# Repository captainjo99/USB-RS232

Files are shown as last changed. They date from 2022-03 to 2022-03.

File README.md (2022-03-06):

# USB-RS232

Small USB to RS232 communication module designed in [KiCad](https://www.kicad.org/).

## Front view

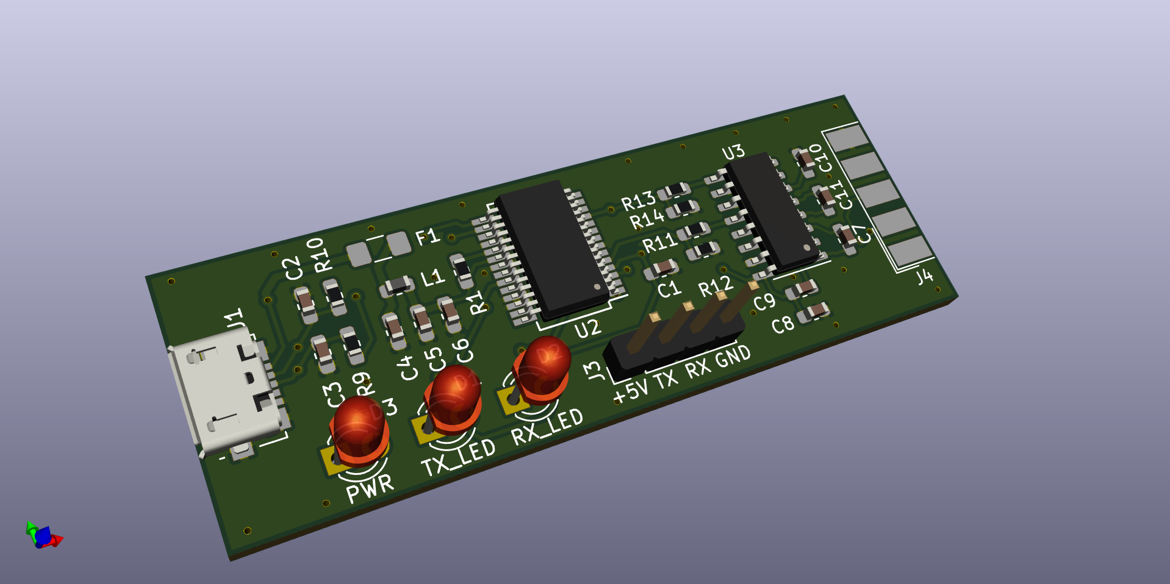
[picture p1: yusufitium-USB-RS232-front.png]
front view


## Back view

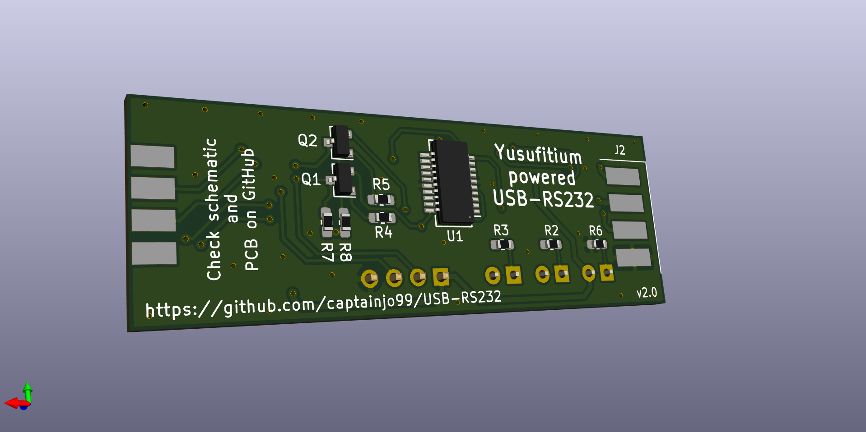
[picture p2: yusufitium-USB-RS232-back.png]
back view


## Notes

This module is based on FT232RL/FT231XS and MAX202.

Schematic is available in pdf format in the repository. Module features 3V3 to 5V level shifter. RX and TX on the pin header arer 5V TTL.

**ONLY USE FT232RL OR FT231XS, NOT BOTH AT THE SAME TIME. MODULE IS DESIGNED SO THEY CAN BE USED INTERCHANGEABLY!!!**

## Licence
Creative Commons Zero 1.0 Universal

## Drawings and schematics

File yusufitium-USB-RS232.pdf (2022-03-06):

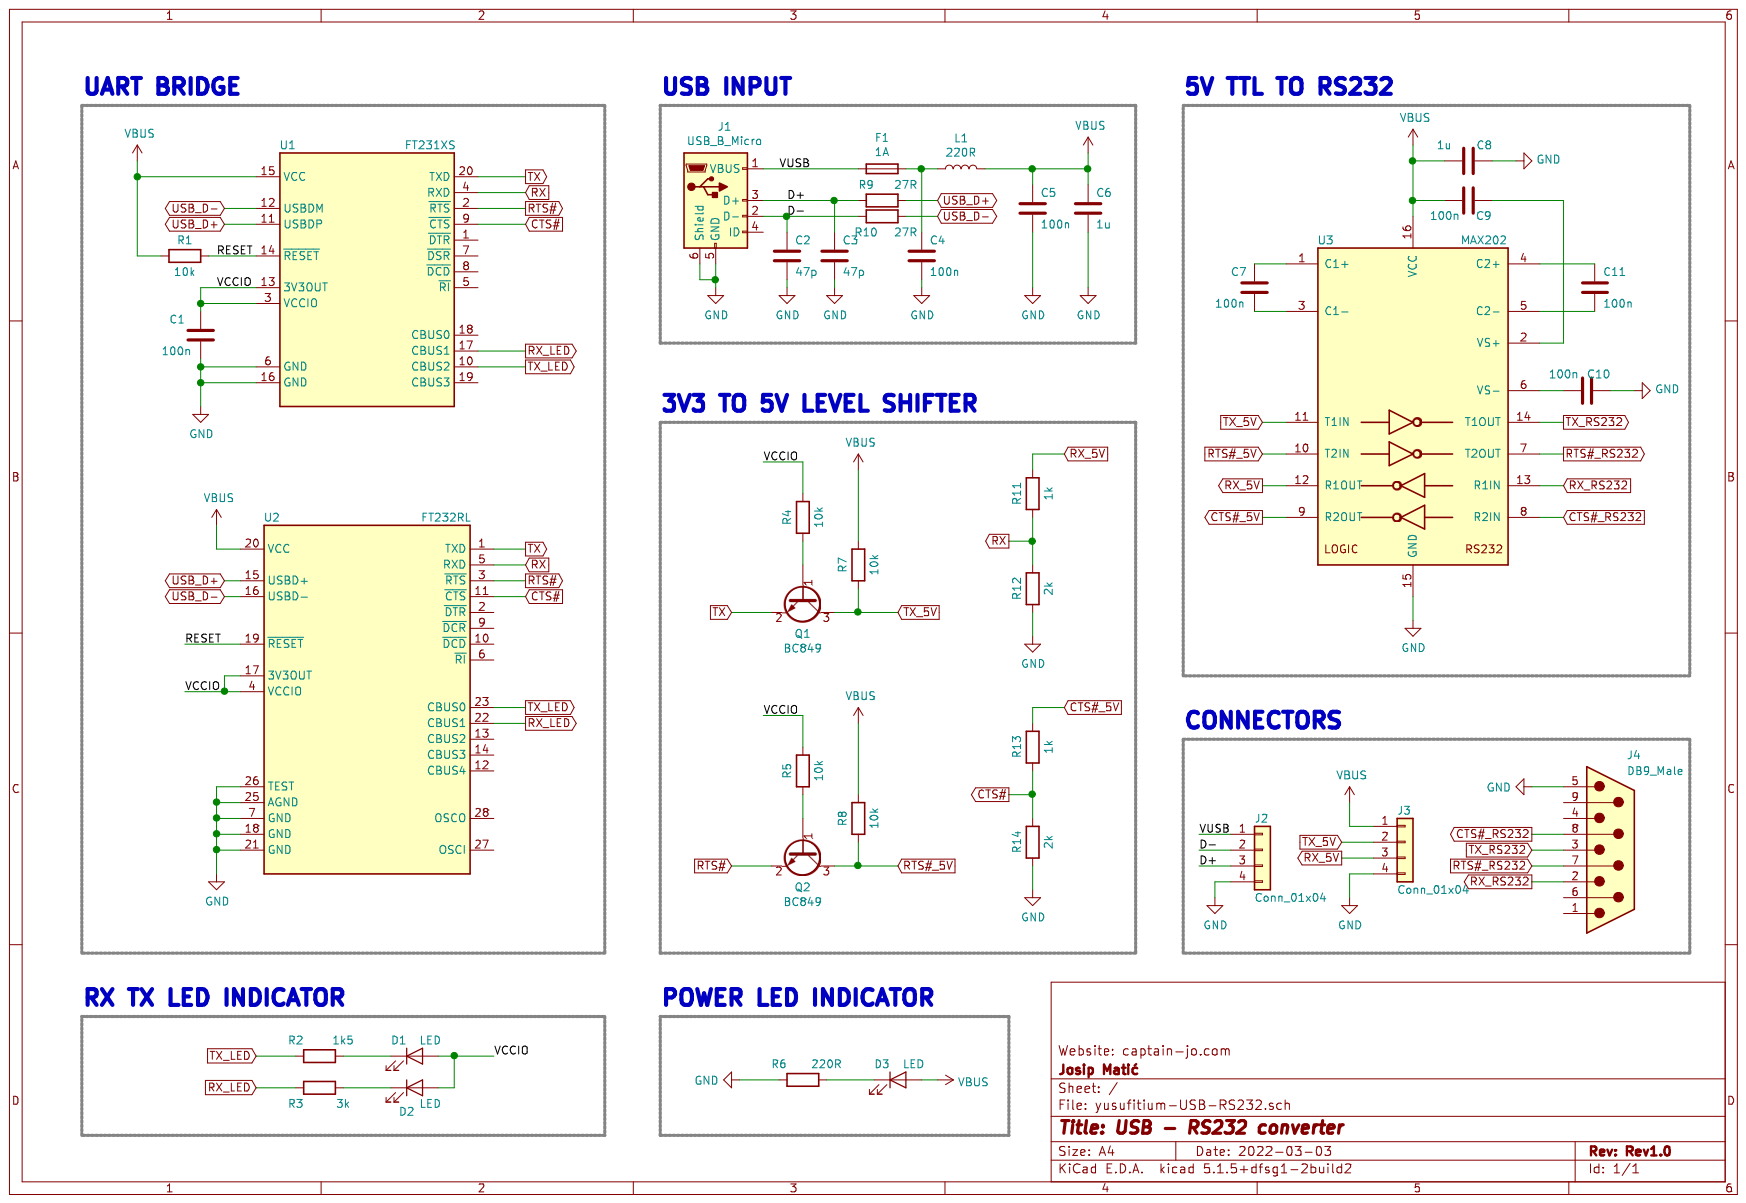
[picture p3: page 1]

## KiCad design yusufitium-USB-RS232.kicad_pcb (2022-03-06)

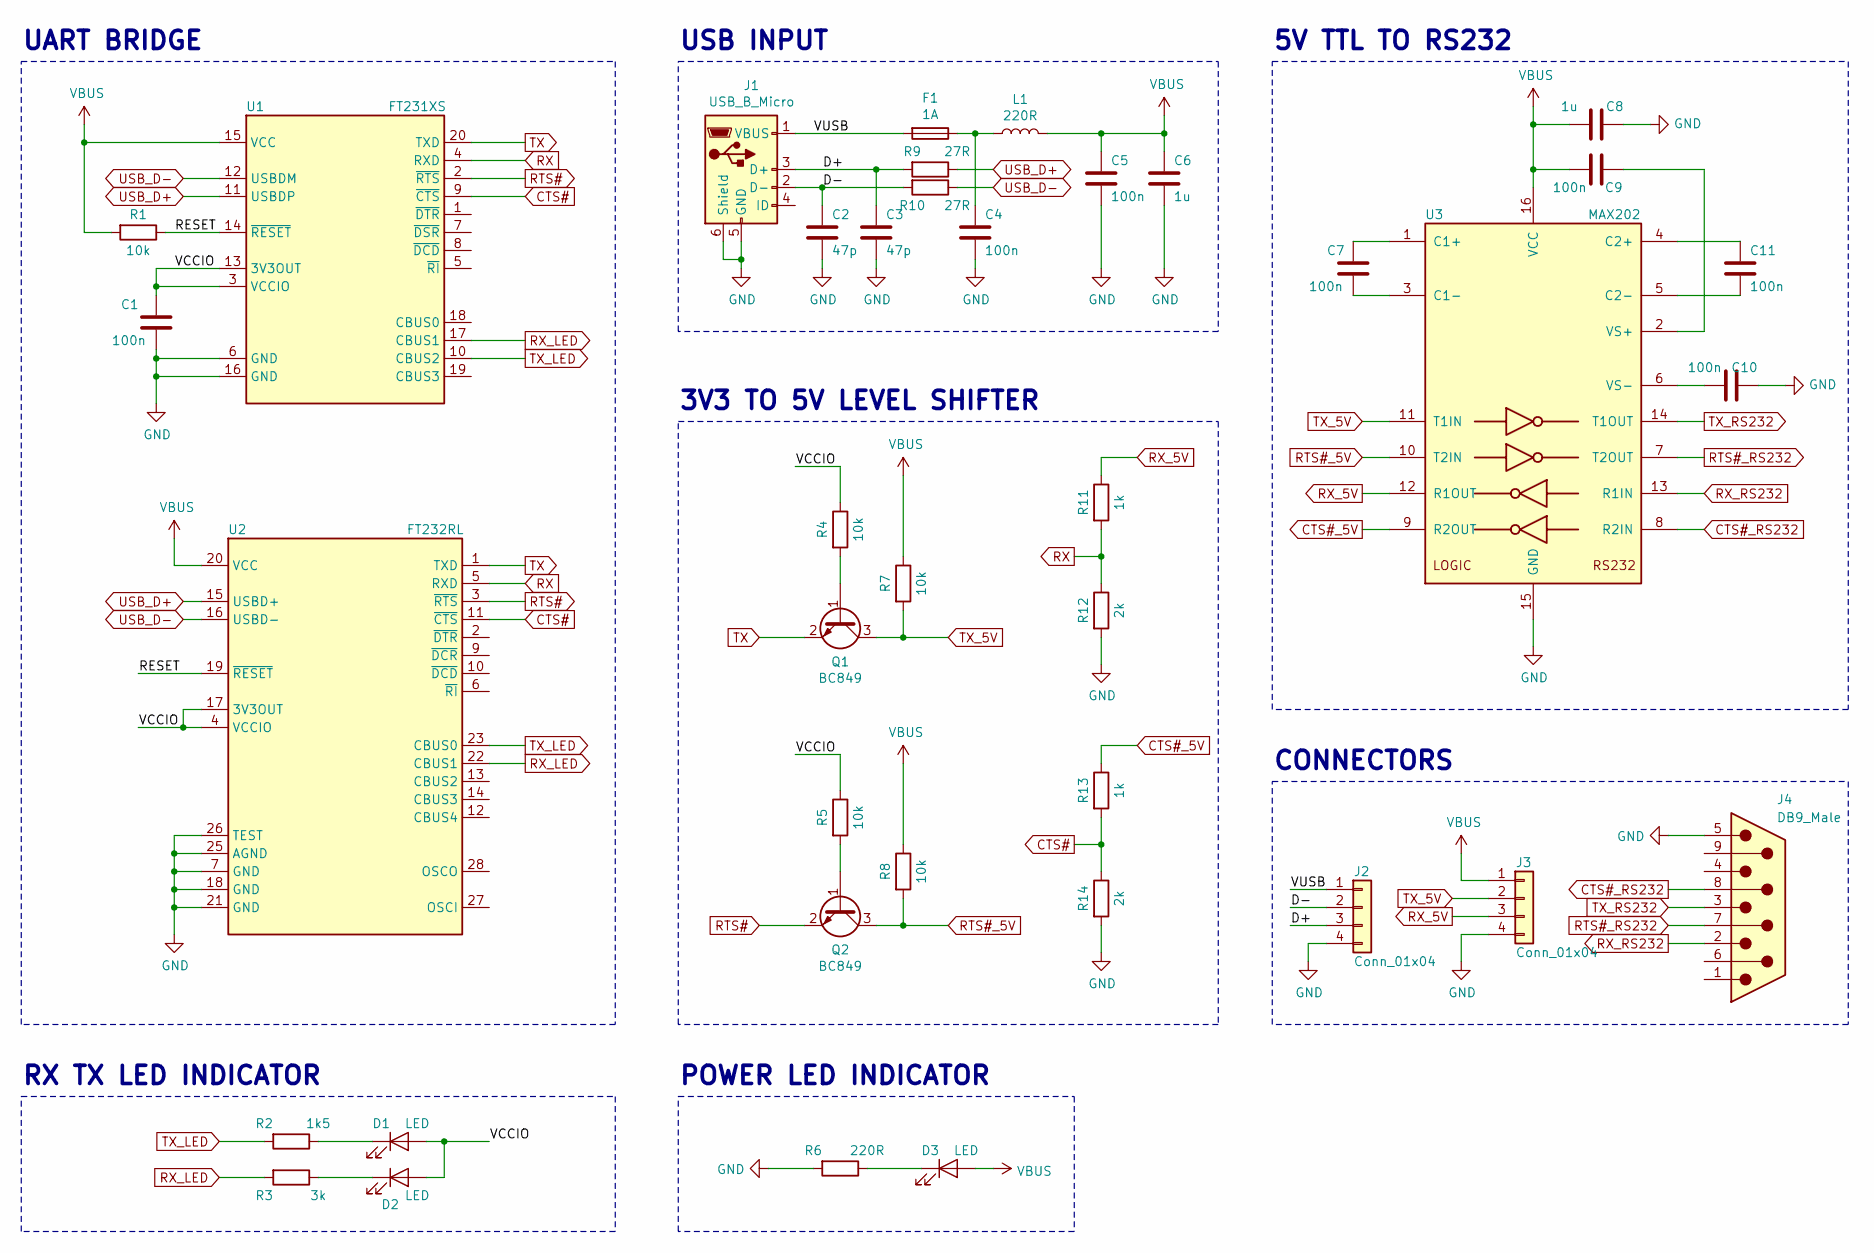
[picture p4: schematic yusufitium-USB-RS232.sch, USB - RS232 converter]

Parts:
C1, C4, C5, C7, C9, C10, C11: 100n; C_0603_1608Metric_Pad1.05x0.95mm_HandSolder
C2, C3: 47p; C_0603_1608Metric_Pad1.05x0.95mm_HandSolder
C6, C8: 1u; C_0603_1608Metric_Pad1.05x0.95mm_HandSolder
D1, D2, D3: LED; LED_D3.0mm
F1: 1A; Fuse_1206_3216Metric_Pad1.42x1.75mm_HandSolder
J1: USB_B_Micro; USB_Micro-B_Molex_47346-0001
J2: Conn_01x04; WireHeader_1x4
J3: Conn_01x04; PinHeader_1x04_P2.54mm_Vertical
J4: DB9_Male; DSUB-9_Male_EdgeMount_P2.77mm
L1: 220R; L_0603_1608Metric
Q1, Q2: BC849; SOT-23
R1, R4, R5, R7, R8: 10k; R_0603_1608Metric_Pad1.05x0.95mm_HandSolder
R2: 1k5; R_0603_1608Metric_Pad1.05x0.95mm_HandSolder
R3: 3k; R_0603_1608Metric_Pad1.05x0.95mm_HandSolder
R6: 220R; R_0603_1608Metric_Pad1.05x0.95mm_HandSolder
R9, R10: 27R; R_0603_1608Metric_Pad1.05x0.95mm_HandSolder
R11, R13: 1k; R_0603_1608Metric_Pad1.05x0.95mm_HandSolder
R12, R14: 2k; R_0603_1608Metric_Pad1.05x0.95mm_HandSolder
U1: FT231XS; SSOP-20_3.9x8.7mm_P0.635mm
U2: FT232RL; SSOP-28_5.3x10.2mm_P0.65mm
U3: MAX202; SOIC-16_3.9x9.9mm_P1.27mm

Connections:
/D+: C3.1, J1.3 (D+), J2.3, R9.2
/D-: C2.1, J1.2 (D-), J2.2, R10.2
/RESET: R1.1, U1.14 (~RESET), U2.19 (~RESET~)
/VCCIO: C1.1, D1.2 (A), D2.2 (A), R4.1, R5.1, U1.3 (VCCIO), U1.13 (3V3OUT), U2.4 (VCCIO), U2.17 (3V3OUT)
/VUSB: F1.2, J1.1 (VBUS), J2.1
CTS#: R13.2, R14.1, U1.9 (~CTS), U2.11 (~CTS)
CTS#_5V: R13.1, U3.9 (R2OUT)
CTS#_RS232: J4.8, U3.8 (R2IN)
GND: C1.2, C2.2, C3.2, C4.2, C5.2, C6.2, C8.1, C10.2, J1.5 (GND), J1.6 (Shield), J2.4, J3.4, J4.5, R6.2, R12.2, R14.2, U1.6 (GND), U1.16 (GND), U2.7 (GND), U2.18 (GND), U2.21 (GND), U2.25 (AGND), U2.26 (TEST), U3.15 (GND)
unnamed: C4.1, F1.1, L1.1
unnamed: C7.1, U3.1 (C1+)
unnamed: C7.2, U3.3 (C1-)
unnamed: C9.2, U3.2 (VS+)
unnamed: C10.1, U3.6 (VS-)
unnamed: C11.1, U3.4 (C2+)
unnamed: C11.2, U3.5 (C2-)
unnamed: D1.1 (K), R2.1
unnamed: D2.1 (K), R3.1
unnamed: D3.1 (K), R6.1
unnamed: Q1.1 (B), R4.2
unnamed: Q2.1 (B), R5.2
RTS#: Q2.2 (E), U1.2 (~RTS), U2.3 (~RTS)
RTS#_5V: Q2.3 (C), R8.2, U3.10 (T2IN)
RTS#_RS232: J4.7, U3.7 (T2OUT)
RX: R11.2, R12.1, U1.4 (RXD), U2.5 (RXD)
RX_5V: J3.3, R11.1, U3.12 (R1OUT)
RX_LED: R3.2, U1.17 (CBUS1), U2.22 (CBUS1)
RX_RS232: J4.2, U3.13 (R1IN)
TX: Q1.2 (E), U1.20 (TXD), U2.1 (TXD)
TX_5V: J3.2, Q1.3 (C), R7.2, U3.11 (T1IN)
TX_LED: R2.2, U1.10 (CBUS2), U2.23 (CBUS0)
TX_RS232: J4.3, U3.14 (T1OUT)
USB_D+: R9.1, U1.11 (USBDP), U2.15 (USBD+)
USB_D-: R10.1, U1.12 (USBDM), U2.16 (USBD-)
VBUS: C5.1, C6.1, C8.2, C9.1, D3.2 (A), J3.1, L1.2, R1.2, R7.1, R8.1, U1.15 (VCC), U2.20 (VCC), U3.16 (VCC)

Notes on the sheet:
UART BRIDGE
USB INPUT
3V3 TO 5V LEVEL SHIFTER
5V TTL TO RS232
CONNECTORS
RX TX LED INDICATOR
POWER LED INDICATOR

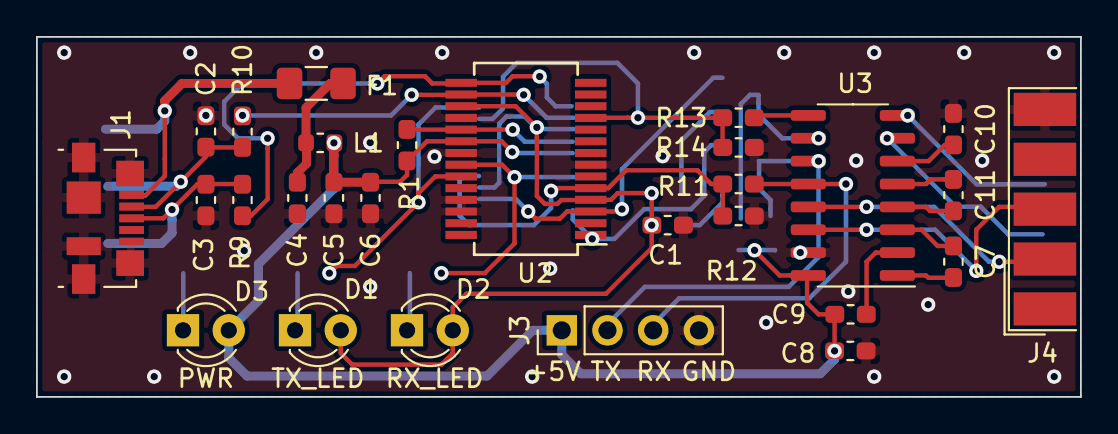
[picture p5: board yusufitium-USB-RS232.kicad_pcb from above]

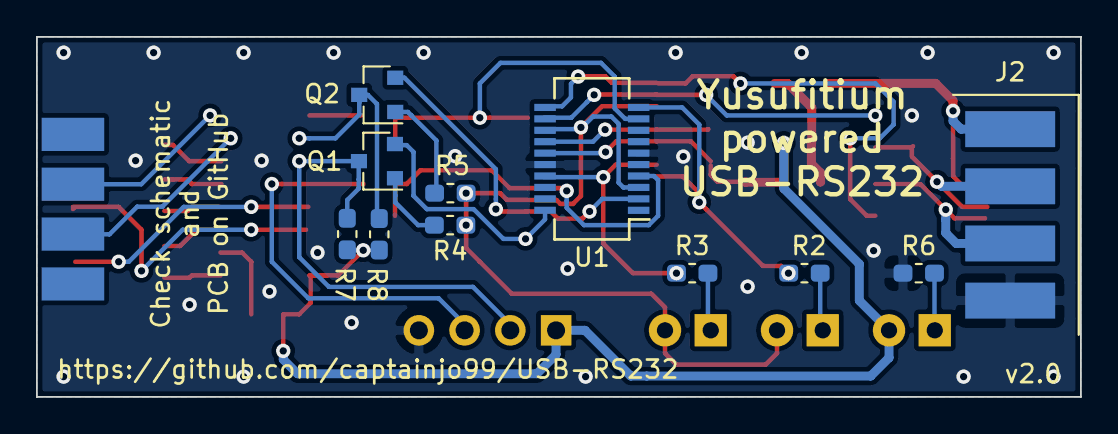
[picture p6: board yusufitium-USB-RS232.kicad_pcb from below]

Board: 2 copper layers, 58.0 x 20.0 mm, 39 parts (11 on the bottom side), 35 nets.
